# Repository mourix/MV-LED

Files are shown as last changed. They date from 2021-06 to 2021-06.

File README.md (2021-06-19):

# MV-LED Reproduction
This is a complete reverse engineering and redrawing of the SNK MV-LED credit counter board. When I restored my Neo Geo cab I found out the prices of these boards are starting to skyrocket. I got myself a damaged MV-LED, scanned the stripped PCBs and figured out the schematics from there. The result is a working copy of the original board you can order and assemble yourself!

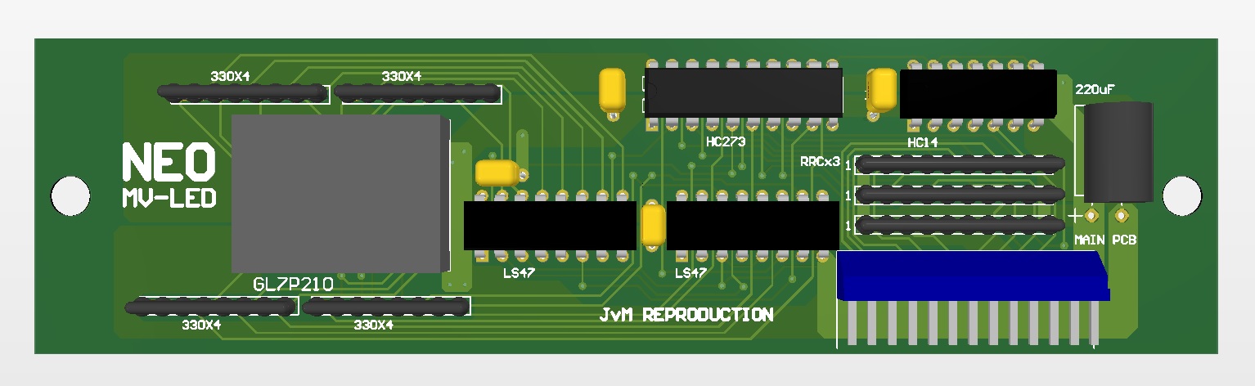
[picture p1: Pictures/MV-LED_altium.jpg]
MV-LED_altium


# How do I make one?
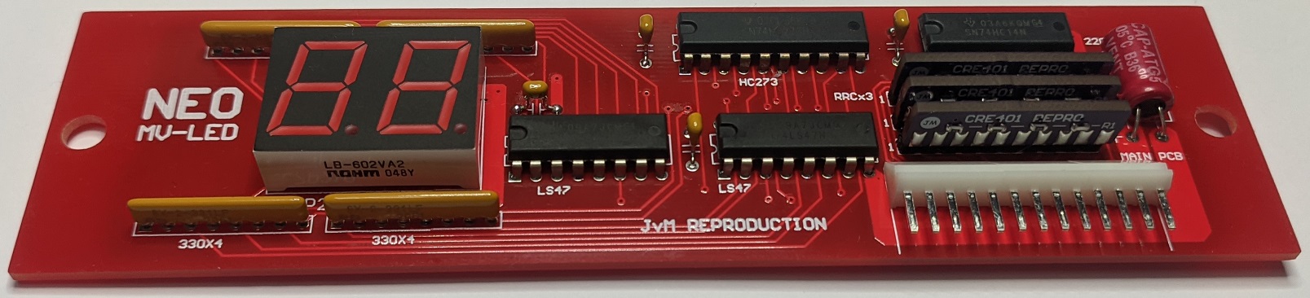
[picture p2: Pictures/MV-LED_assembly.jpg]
MV-LED_assembly


## Bill of Materials
You need the following items for one unit:

|Part|Amount|
|--|--|
|220uF 10V polarized capacitor|1|
|100nF 50V ceramic capacitor|4|
|CRE401 RRC array|3|
|LB-602VA2 display|1|
|JST BS13P-SHF-1AA|1|
|Resistor array 330R|4|
|74HC273|1|
|74HC14|1|
|74LS47|2|
|MV-LED PCB|1|

## PCB
The MV-LED is a 150x40mm 1.6mm PCB. I used JLCPCB rules, but these gerbers will probably work with your fab.

## CRE401
The CRE401 RRC array is out of production, but I got you covered! [Check out the CRE401 Reproduction.](https://github.com/mourix/CRE401)

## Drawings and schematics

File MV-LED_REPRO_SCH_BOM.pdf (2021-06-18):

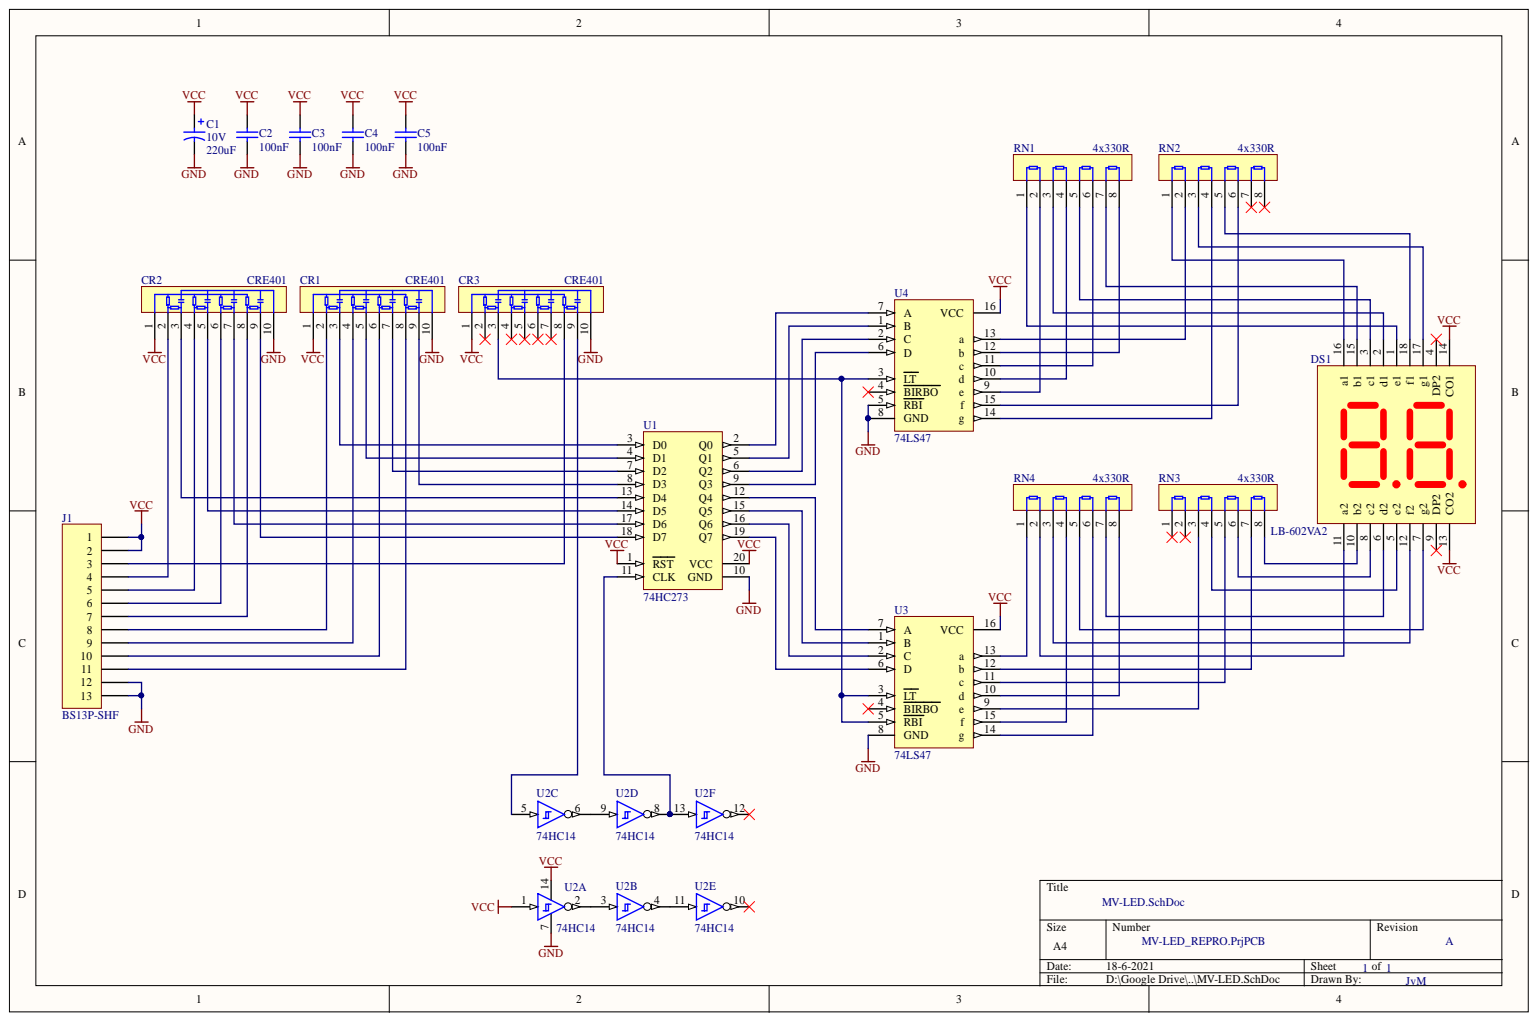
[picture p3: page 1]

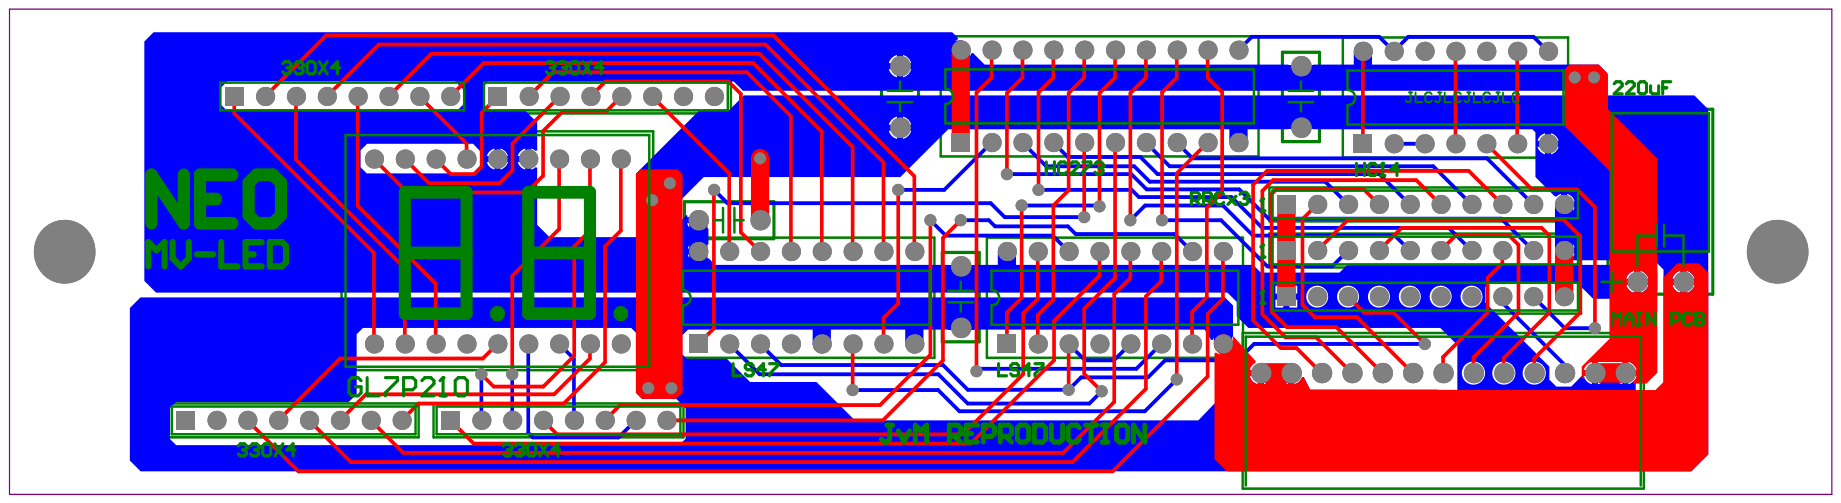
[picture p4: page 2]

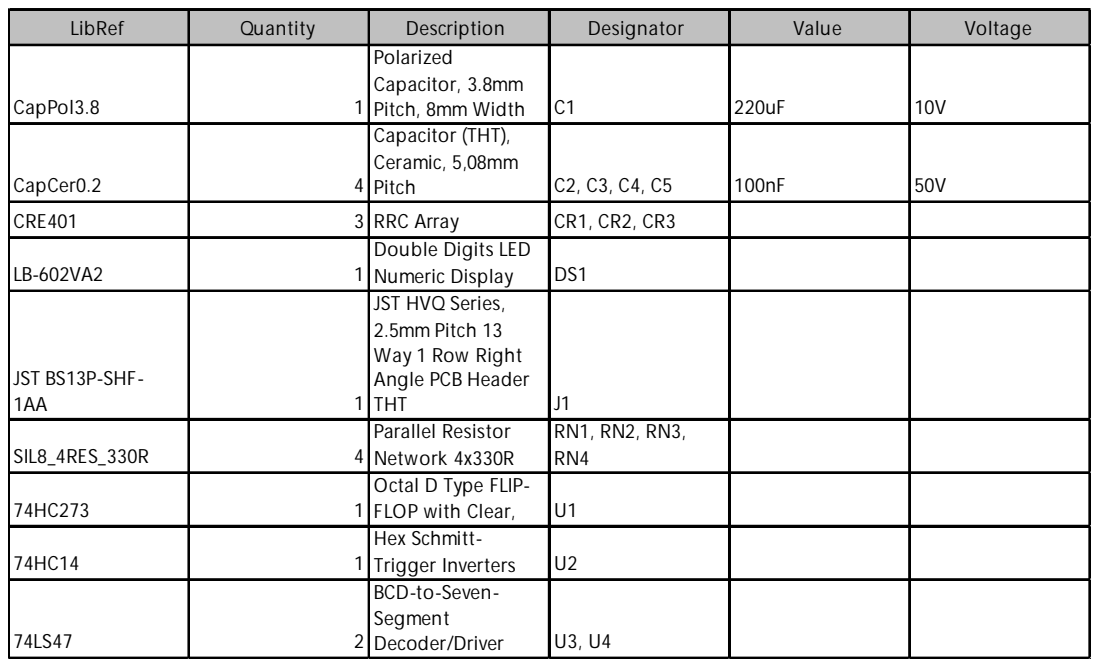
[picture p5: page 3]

LibRef | Quantity | Description | Designator | Value | Voltage

CapPol3.8 | 1 | Polarized Capacitor, 3.8mm Pitch, 8mm Width | C1 | 220uF | 10V

CapCer0.2 | 4 | Capacitor (THT), Ceramic, 5,08mm Pitch | C2, C3, C4, C5 | 100nF | 50V

CRE401 | 3 | RRC Array | CR1, CR2, CR3
LB-602VA2 | 1 | Double Digits LED Numeric Display | DS1

JST BS13P-SHF-1AA | 1 | JST HVQ Series, 2.5mm Pitch 13 Way 1 Row Right Angle PCB Header THT | J1

SIL8_4RES_330R | 4 | Parallel Resistor Network 4x330R | RN1, RN2, RN3, RN4

74HC273 | 1 | Octal D Type FLIP-FLOP with Clear, | U1

74HC14 | 1 | Hex Schmitt-Trigger Inverters | U2

74LS47 | 2 | BCD-to-Seven-Segment Decoder/Driver | U3, U4

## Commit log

2021-06-18 Upload sources and gerbers
    [MV-LED.PcbDoc, MV-LED.PcbLib, MV-LED.SchDoc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]
2021-06-19 Upload PCB scans and assembly pic
